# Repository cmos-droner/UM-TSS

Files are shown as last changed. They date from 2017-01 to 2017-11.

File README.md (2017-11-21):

# UM-TSS - CMOS Drumsynth
This is a circuit by Jacob Watters ([check the original block post](http://www.jacobwatters.com/blog/um-tss-drum-machine/)), I just did the PCB-layout. In agreement with Jacob this is released here as open hardware. Hopefully you enjoy the project and maybe you can even improve it!

## The circuit
The circuit is based around a couple of 40106 hex-schmitt triggers. I removed the divider from Jacobs layout to make every sound triggerable by itself. The trigger ins are protected by clamping diodes.

## PCB v1
PCB v1 has a couple of bugs (mainly because I used the wrong revision of Jacobs circuit **duh**). But the PCB can certainly be used to build a running circuit. Check the build guide for PCB rev. 1 [here](https://github.com/tommueller/UM-TSS/blob/master/schematics%20v1/BUILD.md) and the [BOM](https://github.com/tommueller/UM-TSS/blob/master/schematics%20v1/BOM.ods?raw=true)

## PCB v2
I already fixed most of the issued in the schematics for version 2. I hope that together we can make a second version of the PCB that runs more smooth!

## Case
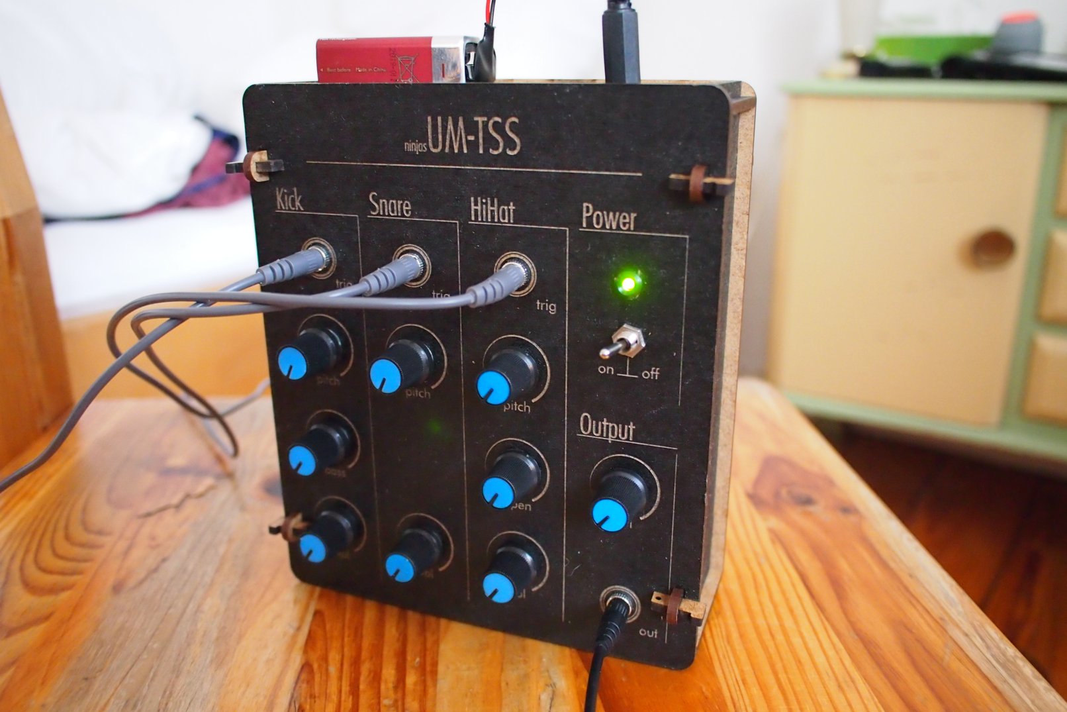
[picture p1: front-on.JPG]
UM-TSS first prototype
I created a case which can be fabbed by a lasercutter. The SVG is available in the repo. The plans are for 3mm material! Here is an image of the first finished prototype (3mm colored HDF):

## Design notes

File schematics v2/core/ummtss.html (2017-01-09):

# BOM Rev

Date

Company

Comment 1

Comment 2

Comment 3

Comment 4

Total Parts

# 75 (Unique 31)

Ref

Qty

Value

Footprint

[C] -

C9

1

10uF

Capacitors_ThroughHole:C_Radial_D5_L11_P2.5

C5

1

470nF

synth-diy:C_Rect_L4.5_W2.5_P3

C7 C20 C22 C8

4

100nF

synth-diy:C_Rect_L4.5_W2.5_P3

C10

1

82nF

synth-diy:C_Rect_L4.5_W2.5_P3

C14 C18

2

10nF

synth-diy:C_Rect_L4.5_W2.5_P3

C24 C13 C12

3

8.2nF

synth-diy:C_Rect_L4.5_W2.5_P3

C19

1

220pF

synth-diy:C_Rect_L4.5_W2.5_P3

C16 C15 C26 C21 C17 C23 C25 C4

8

1uF

Capacitors_ThroughHole:C_Radial_D5_L11_P2.5

C3

1

220uF

Capacitors_ThroughHole:C_Radial_D8_L11.5_P3.5

C6

1

47uF

Capacitors_ThroughHole:C_Radial_D6.3_L11.2_P2.5

C1

1

4.7uF

Capacitors_ThroughHole:C_Radial_D5_L11_P2.5

C2

1

4.7uf

Capacitors_ThroughHole:C_Radial_D5_L11_P2.5

C11

1

22uF

Capacitors_ThroughHole:C_Radial_D5_L11_P2

[D] -

D6 D11 D10 D1 D8 D7 D4 D5 D13 D14 D9 D12

12

1N4148

Diodes_ThroughHole:Diode_DO-35_SOD27_Horizontal_RM10

D2 D3

2

1N4004

Diodes_ThroughHole:Diode_DO-41_SOD81_Horizontal_RM10

[L] -

L1

1

3.8uH

synth-diy:Resistor_Horizontal_RM7mm_Wide

[P] -

P3

1

Bassdrum

Pin_Headers:Pin_Header_Straight_1x12

P4

1

HiHat

Pin_Headers:Pin_Header_Straight_1x12

P5

1

Snare

Pin_Headers:Pin_Header_Straight_1x10

P1

1

PWR

Pin_Headers:Pin_Header_Straight_1x04

P2

1

Out

Pin_Headers:Pin_Header_Straight_1x05

[R] -

R9

1

1M

synth-diy:Resistor_Horizontal_RM7mm_Wide

R11 R23 R13 R7

4

47k

synth-diy:Resistor_Horizontal_RM7mm_Wide

R14 R20 R1 R2

4

100k

synth-diy:Resistor_Horizontal_RM7mm_Wide

R17 R8 R22

3

33k

synth-diy:Resistor_Horizontal_RM7mm_Wide

R16

1

1.3k

synth-diy:Resistor_Horizontal_RM7mm_Wide

R19 R4 R6 R12 R18 R10 R15

7

10k

synth-diy:Resistor_Horizontal_RM7mm_Wide

R21 R3 R5

3

4.7k

synth-diy:Resistor_Horizontal_RM7mm_Wide

[U] -

U2 U3 U4 U5

4

40106

Housings_DIP:DIP-14_W7.62mm_LongPads

U1

1

TL072

Housings_DIP:DIP-8_W7.62mm_LongPads

U6

1

LM7805CT

TO_SOT_Packages_THT:TO-92_Inline_Wide

# BOM made with KICAD_BOM_WIZARD (https://github.com/HashDefineElectronics/KiCad_BOM_Wizard) (Generated Sa 25 Jun 2016 17:02:25 CEST)

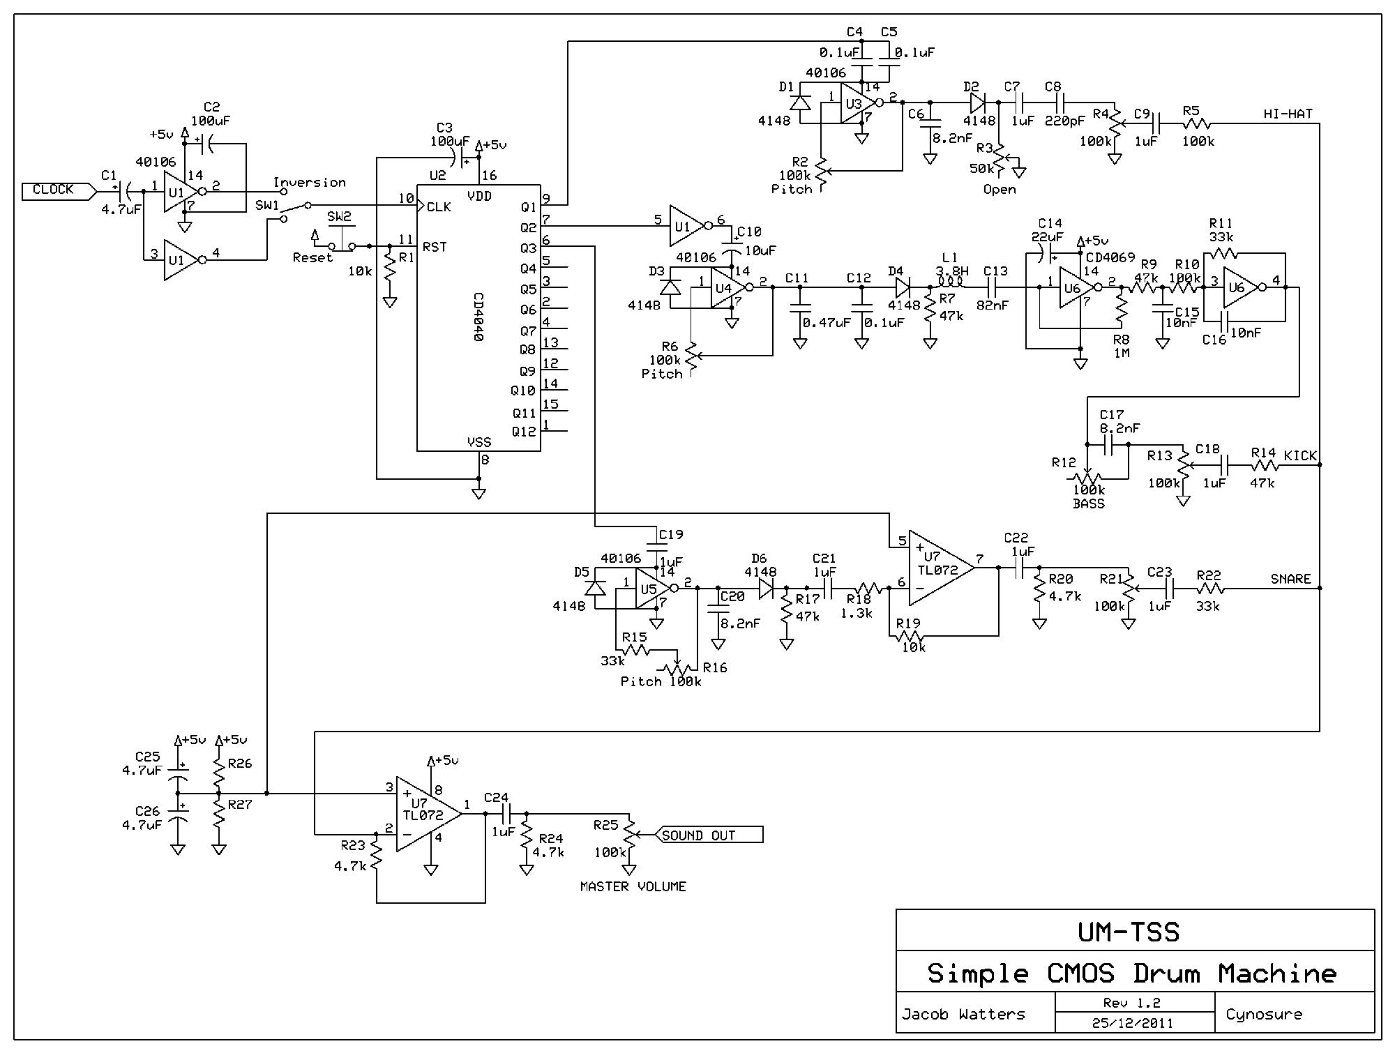
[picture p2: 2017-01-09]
schematics v2/front/cmos drum.gif

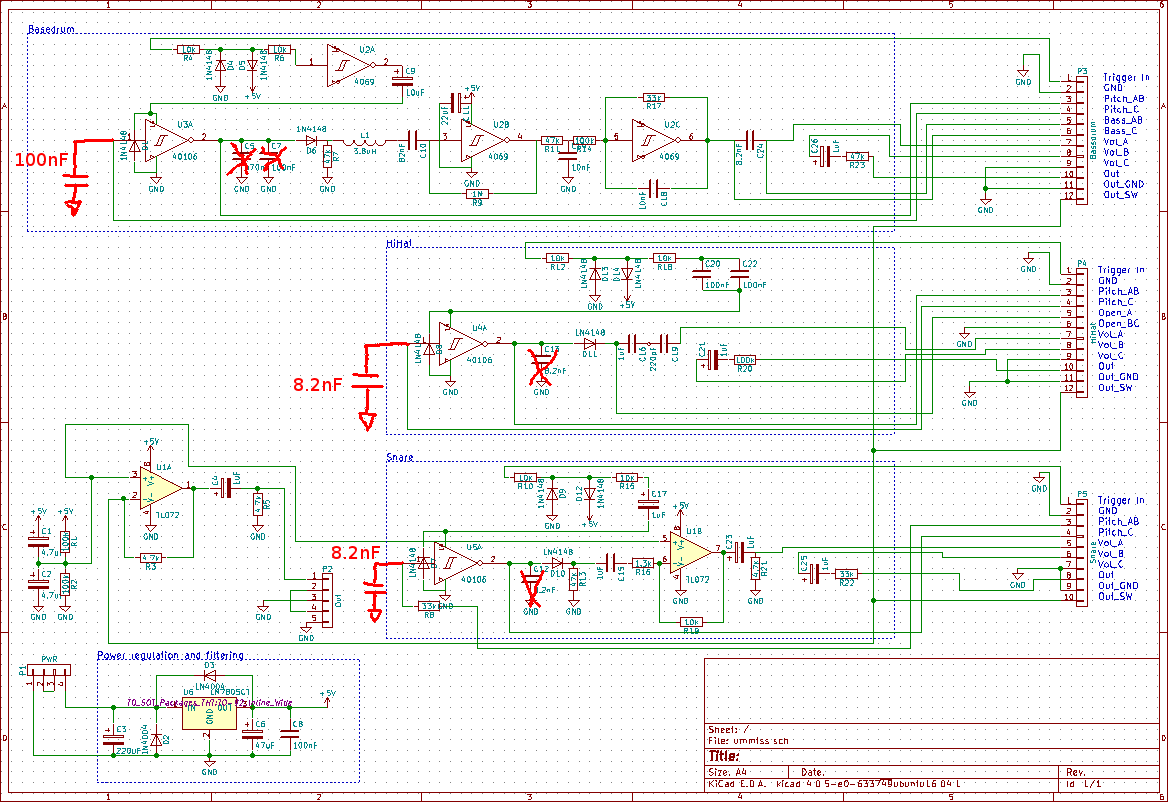
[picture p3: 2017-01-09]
schematics v2/Mine.png

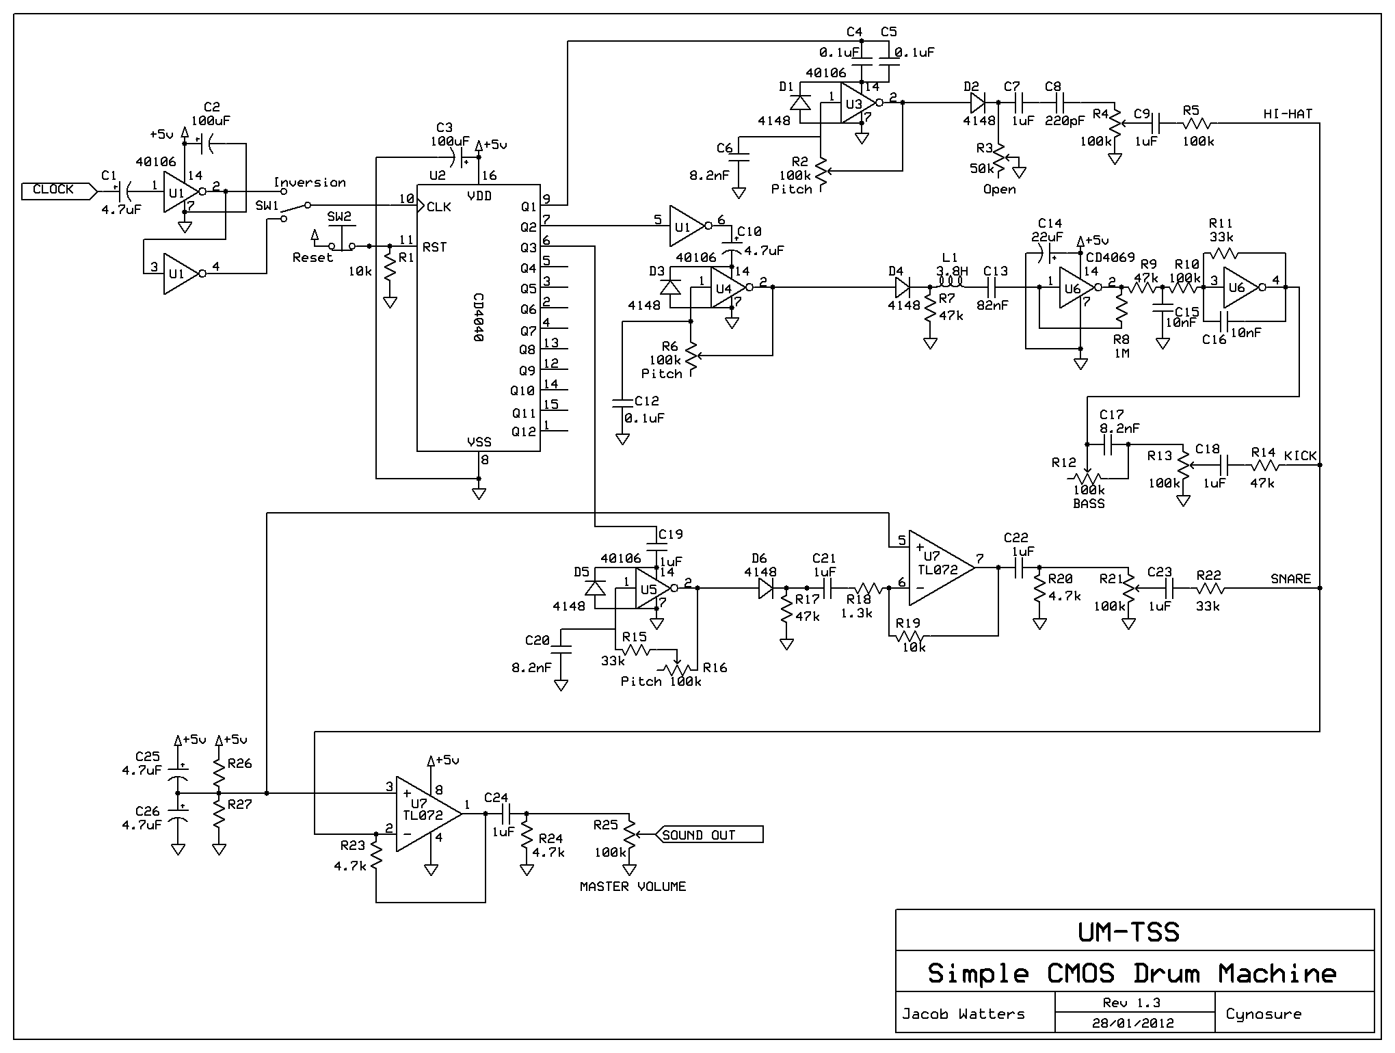
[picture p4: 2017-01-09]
schematics v2/core/download.php.gif

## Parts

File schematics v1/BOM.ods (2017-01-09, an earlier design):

RES
R1, R2 | 100k | 1.3k | 1
R3 | 4.7k | 4.7k | 3
R4 | 10k | 10k | 7
R5 | 4.7k | 33k | 3
R6 | 10k | 47k | 4
R7 | 47k | 100k | 4
R8 | 33k | 1M | 1
R9 | 1M
R10 | 10k
R11 | 47k
R12 | 10k
R13 | 47k
R14 | 100k
R15 | 10k
R16 | 1.3k
R17 | 33k
R18, R19 | 10k
R20 | 100k
R21 | 4.7k
R22 | 33k
R23 | 47k
CAPS
C1, C2 | 4.7uF | 220pF | 1
C3 | 220uF | 8.2nF | 3
C4 | 1uF | 10nF | 2
C5, 7, 12, 12 | - | 82nF | 1
C6 | 47uF | 100nF | 4
C7 | - | 1uF | 8
C8 | 100nF | 4.7uF | 2
C9 | 10uF | 10uF | 1
C10 | 82nF | 22uF | 1
C11 | 22uF | 47uF | 1
C12, C13 | 8.2nF | 220uF | 1
C14 | 10nF
C15, C16, C17 | 1uF
C18 | 10nF
C19 | 220pF
C20 | 100nF
C21 | 1uF
C22 | 100nF
C23 | 1uF
C24 | 8.2nF
C25, C26 | 1uF
DIODES
D1 | 1N4148 | 1N4148 | 12
D2, D3 | 1N4004 | 1N4004 | 2
D4-14 | 1N4148
INDUCTORS
L1 | 3.8uH
SEMI
U1 | TL072
U2 | CD4069
U3, U4, U5 | CD40106
U6 | LM7805
HEADER (all male single row)
P1 | 4
P2 | 5
P3, P4 | 12
P5 | 10
POTS
4xVOL | A100k | A100k | 4
3xPITCH | B100k | B100k | 4
HiHat Open | B50k | B50k | 1
Kick Bass | B100k

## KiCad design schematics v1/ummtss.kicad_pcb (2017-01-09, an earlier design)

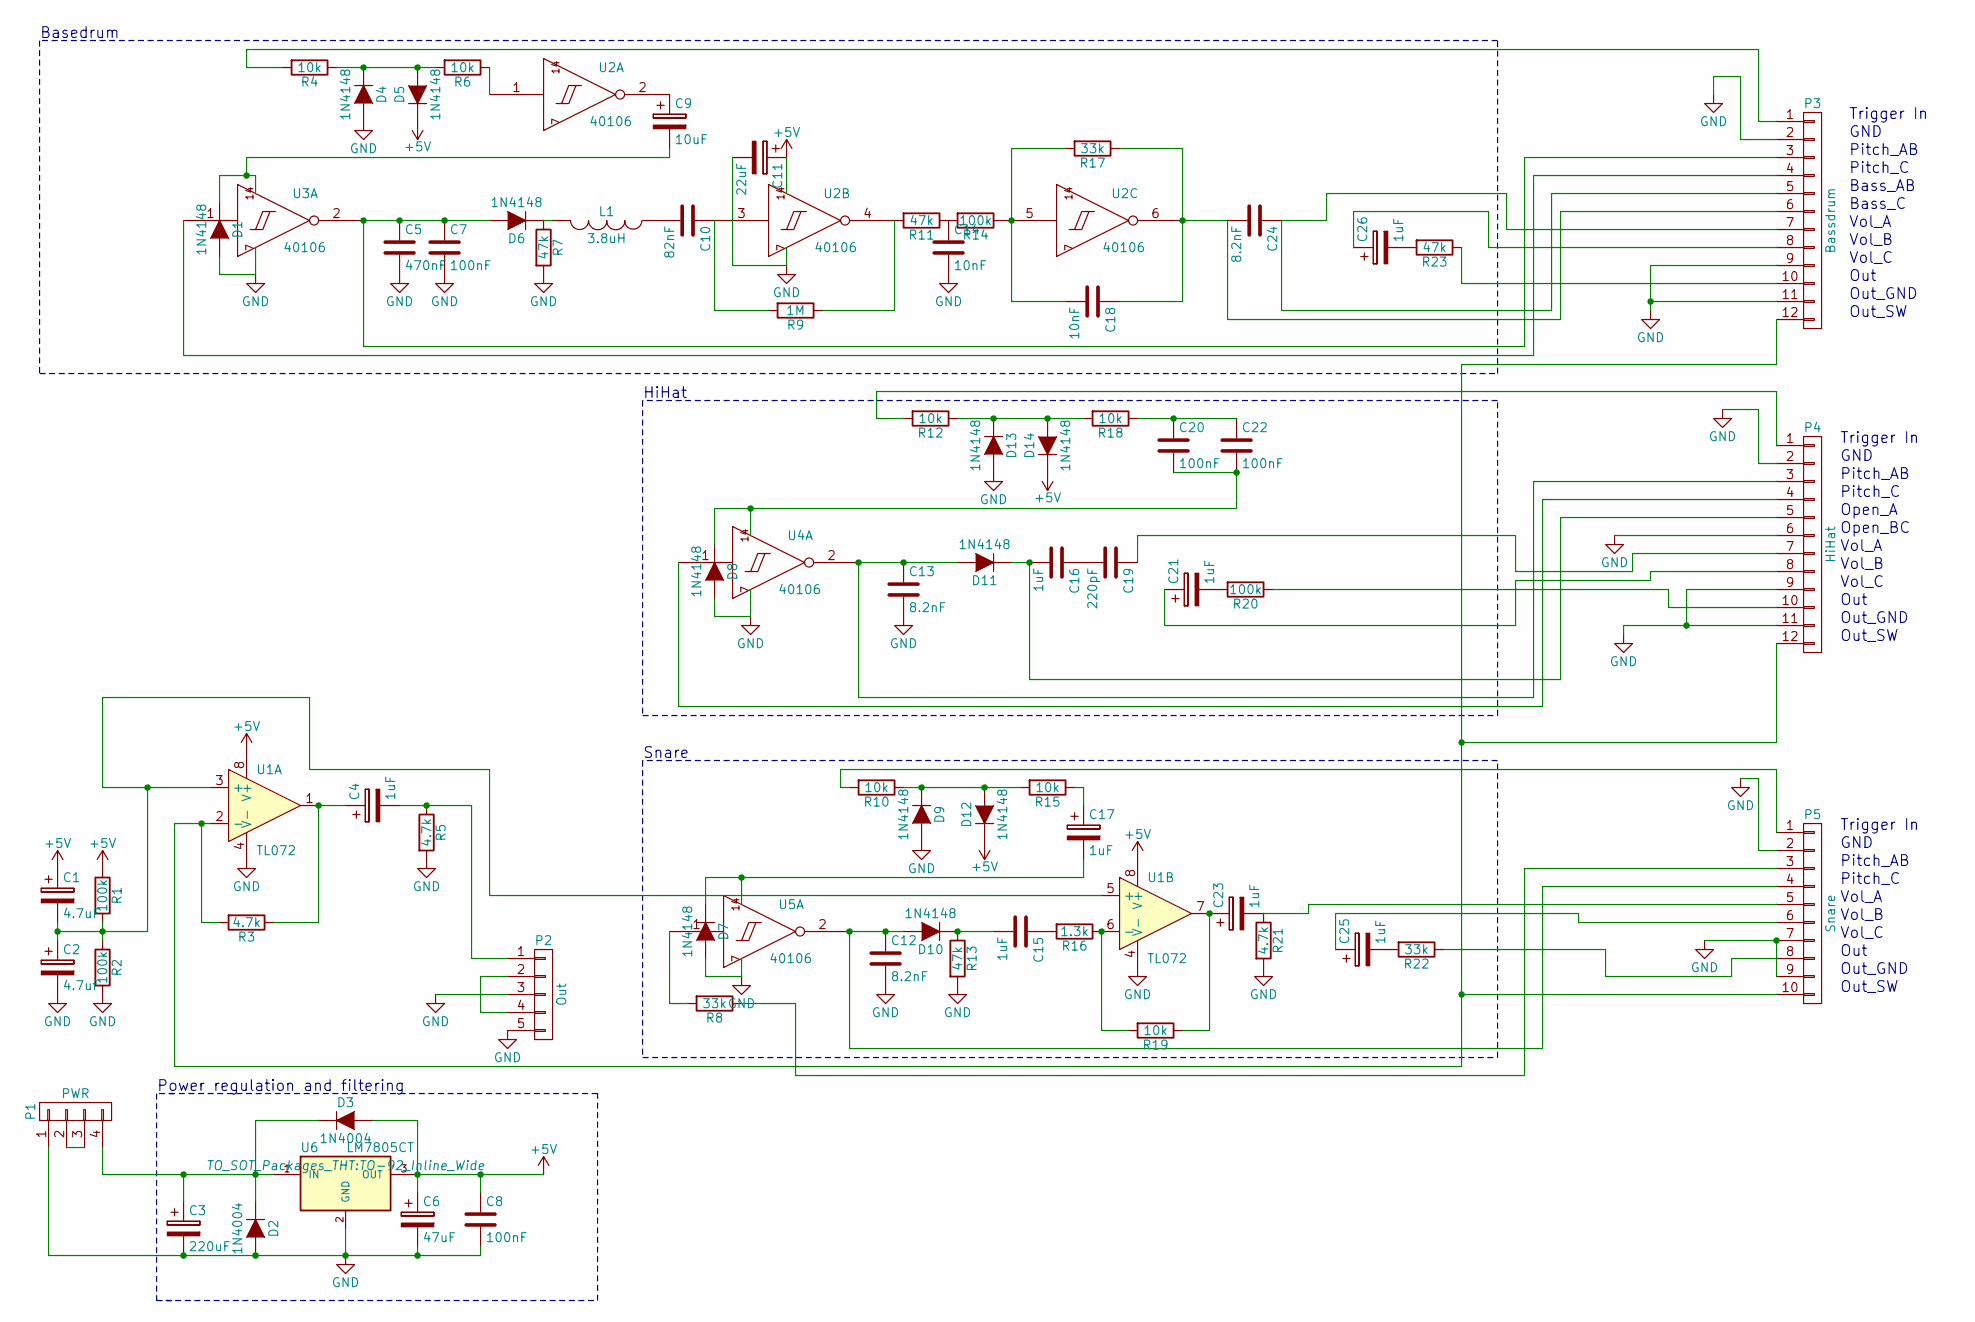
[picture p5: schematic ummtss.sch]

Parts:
C1: 4.7uF; C_Radial_D5_L11_P2.5
C2: 4.7uf; C_Radial_D5_L11_P2.5
C3: 220uF; C_Radial_D8_L11.5_P3.5
C4, C15, C16, C17, C21, C23, C25, C26: 1uF; C_Radial_D5_L11_P2.5
C5: 470nF; C_Rect_L4.5_W2.5_P3
C6: 47uF; C_Radial_D6.3_L11.2_P2.5
C7, C8, C20, C22: 100nF; C_Rect_L4.5_W2.5_P3
C9: 10uF; C_Radial_D5_L11_P2.5
C10: 82nF; C_Rect_L4.5_W2.5_P3
C11: 22uF; C_Radial_D5_L11_P2
C12, C13, C24: 8.2nF; C_Rect_L4.5_W2.5_P3
C14, C18: 10nF; C_Rect_L4.5_W2.5_P3
C19: 220pF; C_Rect_L4.5_W2.5_P3
D1, D4, D5, D6, D7, D8, D9, D10, D11, D12, D13, D14: 1N4148; Diode_DO-35_SOD27_Horizontal_RM10
D2, D3: 1N4004; Diode_DO-41_SOD81_Horizontal_RM10
L1: 3.8uH; Resistor_Horizontal_RM7mm_Wide
P1: PWR; Pin_Header_Straight_1x04
P2: Out; Pin_Header_Straight_1x05
P3: Bassdrum; Pin_Header_Straight_1x12
P4: HiHat; Pin_Header_Straight_1x12
P5: Snare; Pin_Header_Straight_1x10
R1, R2, R14, R20: 100k; Resistor_Horizontal_RM7mm_Wide
R3, R5, R21: 4.7k; Resistor_Horizontal_RM7mm_Wide
R4, R6, R10, R12, R15, R18, R19: 10k; Resistor_Horizontal_RM7mm_Wide
R7, R11, R13, R23: 47k; Resistor_Horizontal_RM7mm_Wide
R8, R17, R22: 33k; Resistor_Horizontal_RM7mm_Wide
R9: 1M; Resistor_Horizontal_RM7mm_Wide
R16: 1.3k; Resistor_Horizontal_RM7mm_Wide
U1: TL072; DIP-8_W7.62mm_LongPads
U2, U3, U4, U5: 40106; DIP-14_W7.62mm_LongPads
U6: LM7805CT; TO-92_Inline_Wide

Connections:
+5V: C1.1, C6.1, C8.1, C11.1, D3.2 (A), D5.1 (K), D12.1 (K), D14.1 (K), R1.1, U1.8 (V+), U2.14 (VDD_IN), U6.3 (OUT)
GND: C2.2, C3.2, C5.2, C6.2, C7.2, C8.2, C11.2, C12.2, C13.2, C14.2, D1.2 (A), D2.2 (A), D4.2 (A), D7.2 (A), D8.2 (A), D9.2 (A), D13.2 (A), P1.1, P2.3, P2.5, P3.2, P3.9, P3.11, P4.2, P4.6, P4.9, P4.11, P5.2, P5.7, P5.9, R2.2, R5.2, R7.2, R13.2, R21.2, U1.4 (V-), U2.7 (VSS_IN), U3.7 (VSS_IN), U4.7 (VSS_IN), U5.7 (VSS_IN), U6.2 (GND); also elsewhere on the board
unnamed: C1.2, C2.1, R1.2, R2.1, U1.3 (+), U1.5 (+)
unnamed 3: C3.1, D2.1 (K), D3.1 (K), P1.4, U6.1 (IN); also elsewhere on the board
unnamed: C4.1, R3.1, U1.1
unnamed 5: C4.2, P2.1, R5.1; also elsewhere on the board
unnamed 6: C5.1, C7.1, D6.2 (A), P3.3, U3.2 (Out); also elsewhere on the board
unnamed: C9.1, U2.2 (Out)
unnamed: C9.2, D1.1 (K), U3.14 (VDD_IN)
unnamed: C10.1, R9.2, U2.3 (In)
unnamed: C10.2, L1.1
unnamed 11: C12.1, D10.2 (A), P5.4, U5.2 (Out); also elsewhere on the board
unnamed 12: C13.1, D11.2 (A), P4.3, U4.2 (Out); also elsewhere on the board
unnamed: C14.1, R11.1, R14.2
unnamed: C15.1, R16.2
unnamed: C15.2, D10.1 (K), R13.1
unnamed: C16.1, C19.2
unnamed 17: C16.2, D11.1 (K), P4.5; also elsewhere on the board
unnamed: C17.1, R15.1
unnamed: C17.2, D7.1 (K), U5.14 (VDD_IN)
unnamed 20: C18.1, C24.2, P3.6, R17.1, U2.6 (Out); also elsewhere on the board
unnamed: C18.2, R17.2
unnamed 22: C19.1, P4.7; also elsewhere on the board
unnamed: C20.1, C22.1, R18.1
unnamed: C20.2, C22.2, D8.1 (K), U4.14 (VDD_IN)
unnamed 25: C21.1, P4.8; also elsewhere on the board
unnamed: C21.2, R20.2
unnamed: C23.1, R19.1, U1.7
unnamed 28: C23.2, P5.5, R21.1; also elsewhere on the board
unnamed 29: C24.1, P3.5, P3.7; also elsewhere on the board
unnamed 30: C25.1, P5.6; also elsewhere on the board
unnamed: C25.2, R22.2
unnamed 32: C26.1, P3.8; also elsewhere on the board
unnamed: C26.2, R23.2
unnamed: D4.1 (K), D5.2 (A), R4.1, R6.2
unnamed: D6.1 (K), L1.2, R7.1
unnamed: D9.1 (K), D12.2 (A), R10.1, R15.2
unnamed: D13.1 (K), D14.2 (A), R12.1, R18.2
unnamed 38: P1.2, P1.3; also elsewhere on the board
unnamed 39: P2.2, P2.4; also elsewhere on the board
unnamed 40: P3.1, R4.2; also elsewhere on the board
unnamed 41: P3.4, U3.1 (In); also elsewhere on the board
unnamed 42: P3.10, R23.1; also elsewhere on the board
unnamed 43: P3.12, P4.12, P5.10, R3.2, U1.2 (-); also elsewhere on the board
unnamed 44: P4.1, R12.2; also elsewhere on the board
unnamed 45: P4.4, U4.1 (In); also elsewhere on the board
unnamed 46: P4.10, R20.1; also elsewhere on the board
unnamed 47: P5.1, R10.2; also elsewhere on the board
unnamed 48: P5.3, R8.1; also elsewhere on the board
unnamed 49: P5.8, R22.1; also elsewhere on the board
unnamed: R6.1, U2.1 (In)
unnamed: R8.2, U5.1 (In)
unnamed: R9.1, R11.2, U2.4 (Out)
unnamed: R14.1, U2.5 (In)
unnamed: R16.1, R19.2, U1.6 (-)

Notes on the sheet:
Basedrum
HiHat
Snare
Power regulation and filtering
Trigger In
GND
Pitch_AB
Pitch_C
Bass_AB
Bass_C
Vol_A
Vol_B
Vol_C
Out
Out_GND
Out_SW
Open_A
Open_BC

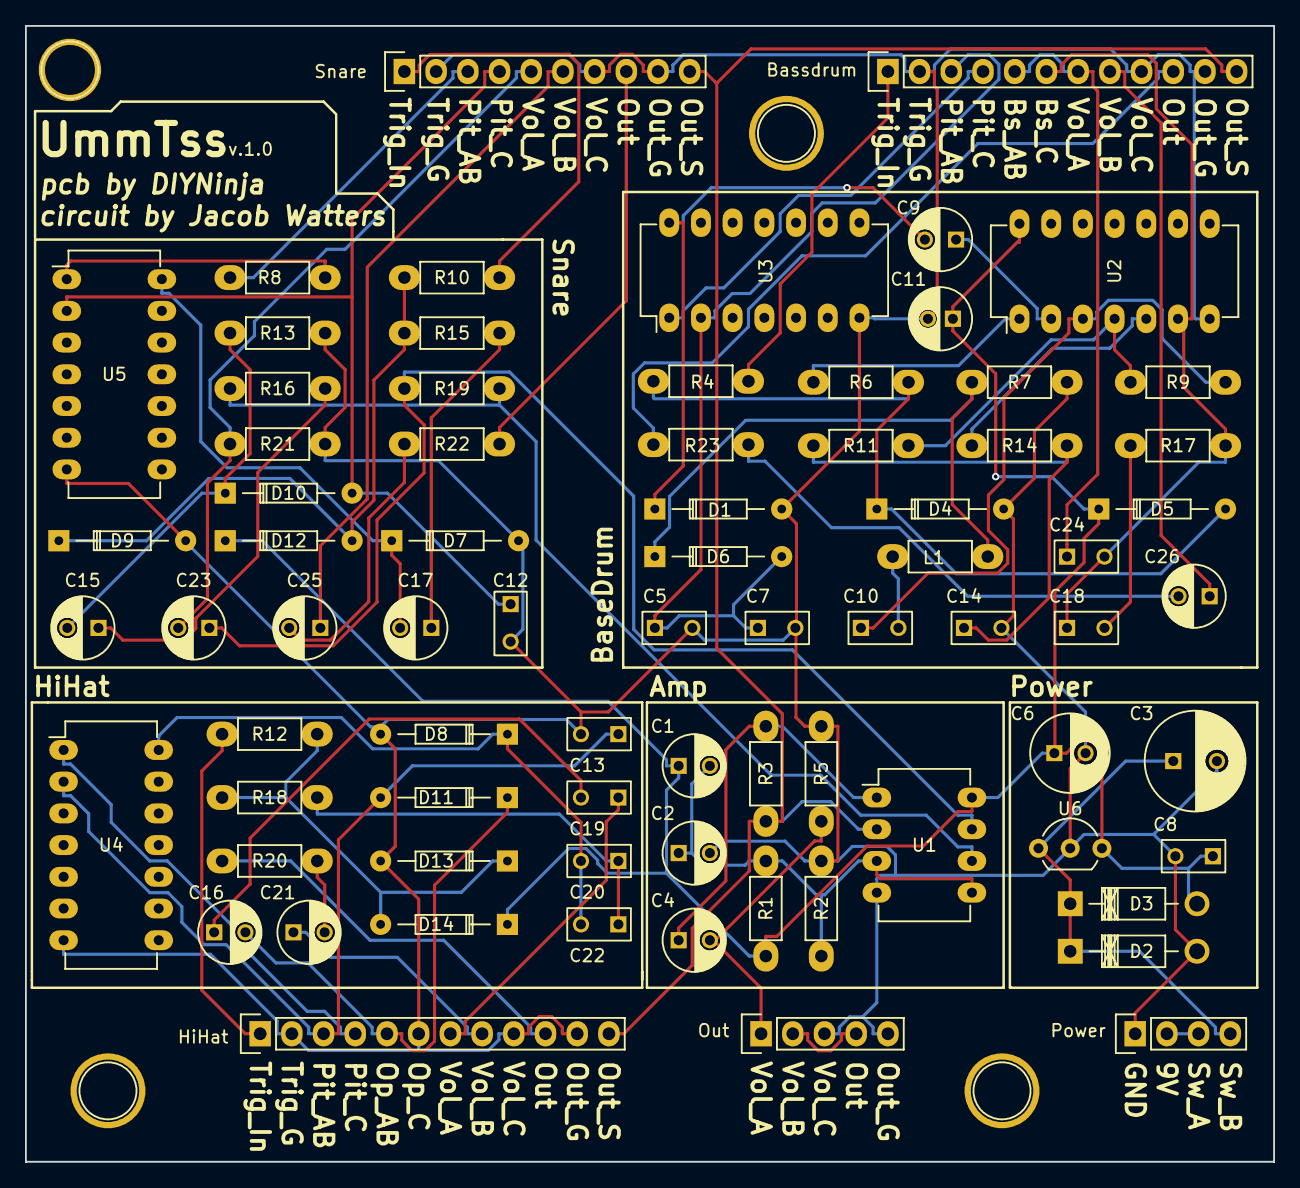
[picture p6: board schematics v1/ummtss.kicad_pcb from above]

Board: 2 copper layers, 100.0 x 91.0 mm, 79 parts (0 on the bottom side), 55 nets.

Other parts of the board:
Bassdrum: Bassdrum; Pin_Header_Straight_1x12
H1, H2, H3, H4: 1pin
HiHat: HiHat; Pin_Header_Straight_1x12
Out: Out; Pin_Header_Straight_1x05
Power: PWR; Pin_Header_Straight_1x04
Snare: Snare; Pin_Header_Straight_1x10

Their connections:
GND: Bassdrum.2, Bassdrum.9, Bassdrum.11, HiHat.2, HiHat.6, HiHat.9, HiHat.11, Out.3, Out.5, Power.1, Snare.2, Snare.7, Snare.9; also elsewhere on the board
unnamed 3: Power.4; also elsewhere on the board
unnamed 5: Out.1; also elsewhere on the board
unnamed 6: Bassdrum.3; also elsewhere on the board
unnamed 11: Snare.4; also elsewhere on the board
unnamed 12: HiHat.3; also elsewhere on the board
unnamed 17: HiHat.5; also elsewhere on the board
unnamed 20: Bassdrum.6; also elsewhere on the board
unnamed 22: HiHat.7; also elsewhere on the board
unnamed 25: HiHat.8; also elsewhere on the board
unnamed 28: Snare.5; also elsewhere on the board
unnamed 29: Bassdrum.5, Bassdrum.7; also elsewhere on the board
unnamed 30: Snare.6; also elsewhere on the board
unnamed 32: Bassdrum.8; also elsewhere on the board
unnamed 38: Power.2, Power.3; also elsewhere on the board
unnamed 39: Out.2, Out.4; also elsewhere on the board
unnamed 40: Bassdrum.1; also elsewhere on the board
unnamed 41: Bassdrum.4; also elsewhere on the board
unnamed 42: Bassdrum.10; also elsewhere on the board
unnamed 43: Bassdrum.12, HiHat.12, Snare.10; also elsewhere on the board
unnamed 44: HiHat.1; also elsewhere on the board
unnamed 45: HiHat.4; also elsewhere on the board
unnamed 46: HiHat.10; also elsewhere on the board
unnamed 47: Snare.1; also elsewhere on the board
unnamed 48: Snare.3; also elsewhere on the board
unnamed 49: Snare.8; also elsewhere on the board

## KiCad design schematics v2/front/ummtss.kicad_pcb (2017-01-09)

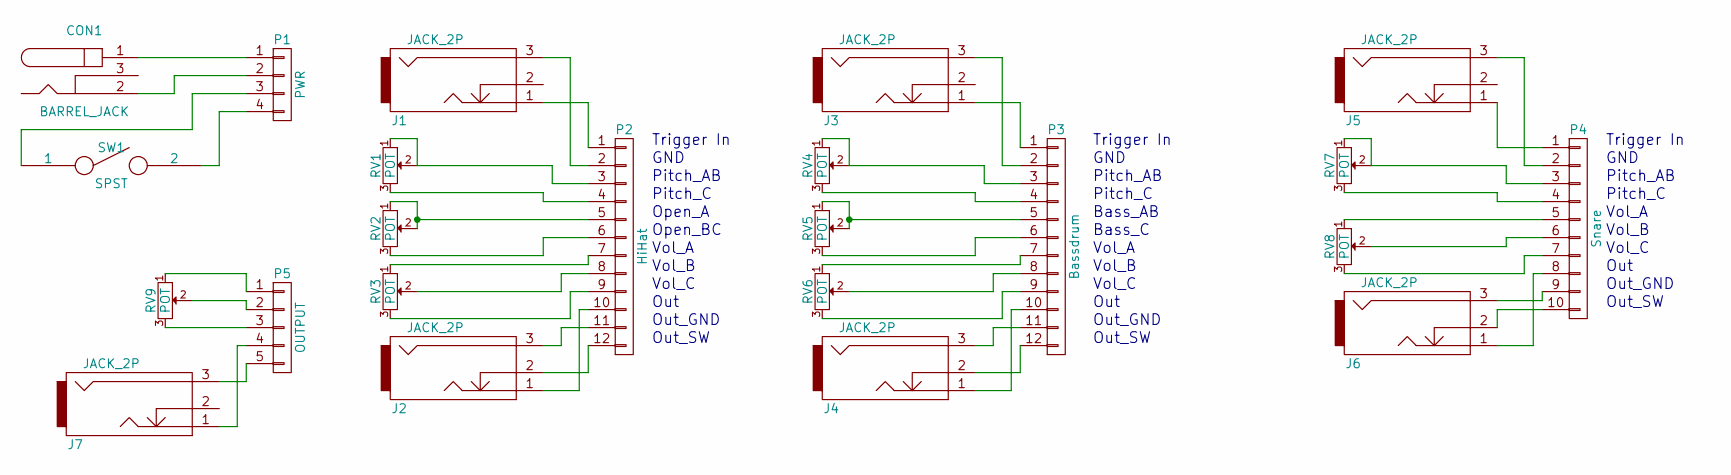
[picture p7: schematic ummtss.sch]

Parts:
CON1: BARREL_JACK
J1, J2, J3, J4, J5, J6, J7: JACK_2P; jack-PJ301M
P1: PWR; Pin_Header_Straight_1x04
P2: HiHat; Pin_Header_Straight_1x12
P3: Bassdrum; Pin_Header_Straight_1x12
P4: Snare; Pin_Header_Straight_1x10
P5: OUTPUT; Pin_Header_Straight_1x05
RV1, RV2, RV3, RV4, RV5, RV6, RV7, RV8, RV9: POT; pot_alpha-9mm--vertical
SW1: SPST; SW_Micro_SPST

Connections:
unnamed: CON1.1, P1.1
unnamed: CON1.2, P1.2
unnamed: J1.1, P2.1
unnamed: J1.3, P2.2
unnamed: J2.1, P2.10
unnamed: J2.2, P2.12
unnamed: J2.3, P2.11
unnamed: J3.1, P3.1
unnamed: J3.3, P3.2
unnamed: J4.1, P3.10
unnamed: J4.2, P3.12
unnamed: J4.3, P3.11
unnamed: J5.1, P4.1
unnamed: J5.3, P4.2
unnamed: J6.1, P4.8
unnamed: J6.2, P4.10
unnamed: J6.3, P4.9
unnamed: J7.1, P5.4
unnamed: J7.3, P5.5
unnamed: P1.3, SW1.1
unnamed: P1.4, SW1.2
unnamed: P2.3, RV1.1, RV1.2
unnamed: P2.4, RV1.3
unnamed: P2.5, RV2.1, RV2.2
unnamed: P2.6, RV2.3
unnamed: P2.7, RV3.1
unnamed: P2.8, RV3.2
unnamed: P2.9, RV3.3
unnamed: P3.3, RV4.1, RV4.2
unnamed: P3.4, RV4.3
unnamed: P3.5, RV5.1, RV5.2
unnamed: P3.6, RV5.3
unnamed: P3.7, RV6.1
unnamed: P3.8, RV6.2
unnamed: P3.9, RV6.3
unnamed: P4.3, RV7.1, RV7.2
unnamed: P4.4, RV7.3
unnamed: P4.5, RV8.1
unnamed: P4.6, RV8.2
unnamed: P4.7, RV8.3
unnamed: P5.1, RV9.1
unnamed: P5.2, RV9.2
unnamed: P5.3, RV9.3

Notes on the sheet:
Trigger In
GND
Pitch_AB
Pitch_C
Bass_AB
Bass_C
Vol_A
Vol_B
Vol_C
Out
Out_GND
Out_SW
Open_A
Open_BC

Board: 2 copper layers, 23 parts (0 on the bottom side), 43 nets, no tracks yet.

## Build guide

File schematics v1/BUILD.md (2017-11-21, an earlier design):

# Build instructions
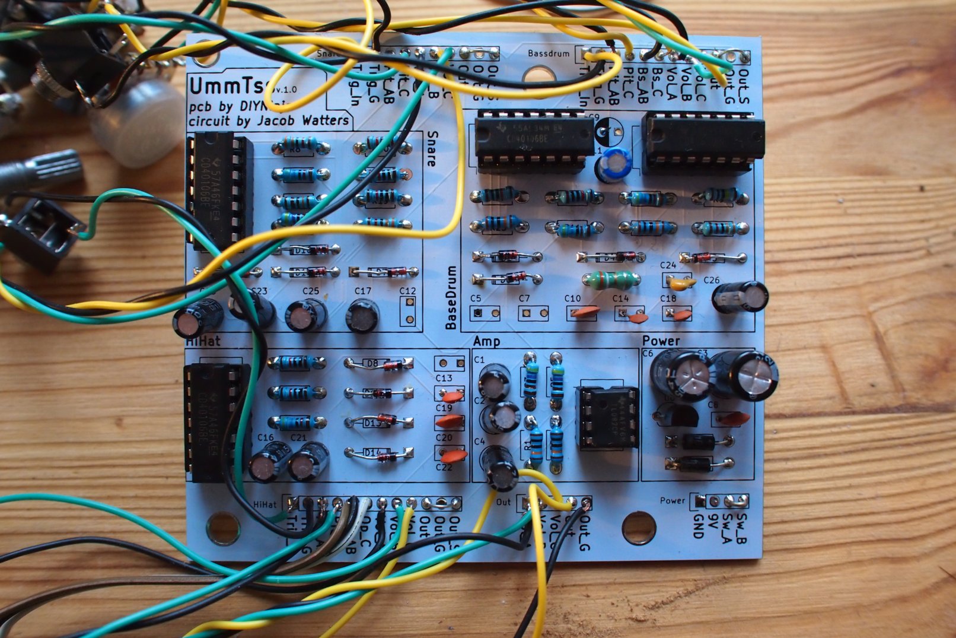
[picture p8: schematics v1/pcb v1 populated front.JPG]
Build the PCB as usual using the [BOM](https://github.com/tommueller/UM-TSS/blob/master/schematics%20v1/BOM.ods?raw=true) **BUT** do not add caps: **C5, C7, C9, C12 and C13**. You can doublecheck with this image: 

When you are finished with this, you need to do the following to get this up and running:

- at the back of the PCB solder a 8.2nF cap between the legs 1 & 7 of U4 and U5 each
- solder a 100nF cap between the legs 1 & 7 of U3
- add a little wire between pins 2 & 13 of U3
- take C9 (10uF) and solder it with its positive side to pin 12 of U3 and the negative side to the negative pad of C9

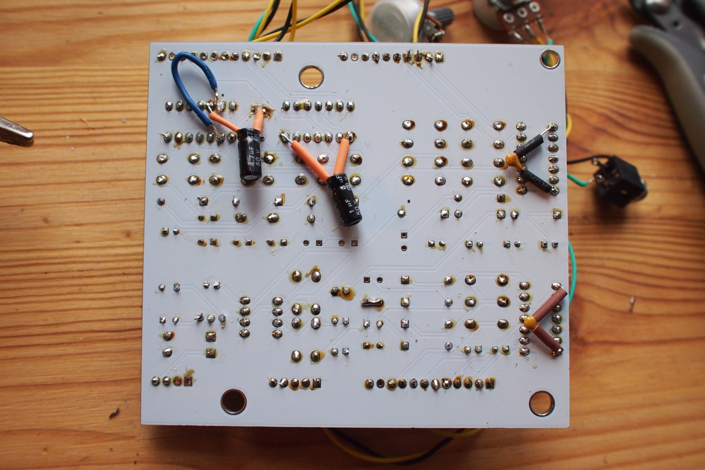
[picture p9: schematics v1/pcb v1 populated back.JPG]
Again you can doublecheck with this image: 

## LED
The resistor for the led is not placed on the pcb. Please wire the led with a 1k resistor in series between + and GND. Do this behind the on/off-switch off course. The LED-mountin hole is 6mm, I used this [led mounting clips](https://www.taydaelectronics.com/3mm-bezel-led-panel-mounting-clip.html).

## DC in
The UM-TSS expects 9V input voltage. The LM7805 has a much wider range though, so anything between 9V and 15V shouldn't be a problem. I use this [dc power jack](https://www.taydaelectronics.com/dc-power-jack-2-1mm-enclosed-frame-with-switch-external.html).

## Wiring
Basically the wiring is self-explaining. Every section of the circuit has its own row of ins-/outs. You can use it to mount headers or just solder the parts in directly. All the solder pads are labeled.

### Pots
The labeling of the pots is not correct! I will add a detailed wiring guide soon!

## Instrument outs
All the "instruments" have a sngle out, which takes it out of the mix as well. These signals do not run through UM-TSS amp, so you will probably need to amplify them!

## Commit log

2017-01-09 Add project files
    [ummtss-B.Cu.gbr, ummtss-B.Mask.gbr, ummtss-B.SilkS.gbr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]
2017-01-09 rename case folder
2017-01-09 remove old note from case
2017-01-09 add material desc
2017-01-09 add bom
    [BOM.ods]
2017-01-09 add bom to readme
2017-01-12 fix twoo small holes in case
2017-01-20 add eps of case
